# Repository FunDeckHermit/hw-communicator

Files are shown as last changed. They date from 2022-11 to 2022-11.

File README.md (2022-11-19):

# HW-communicator
Devices that can communicate state to one another. 

Project uses a Raspberry Pi Pico W, a Lora antenna, TP4056 lithium-ion cell charger to transmit a selected phrase.
This selected phrase is picked up by another module and displayed.

All firmware code is written in micropython. 

Todo: 
 * Wifi communication
 * LoraWAN communication
 * Pickup firmware
 
What would I do differently:
 * Add USB-B port somewhere
 * Add buzzer
 * Move 18650 holder a bit higher





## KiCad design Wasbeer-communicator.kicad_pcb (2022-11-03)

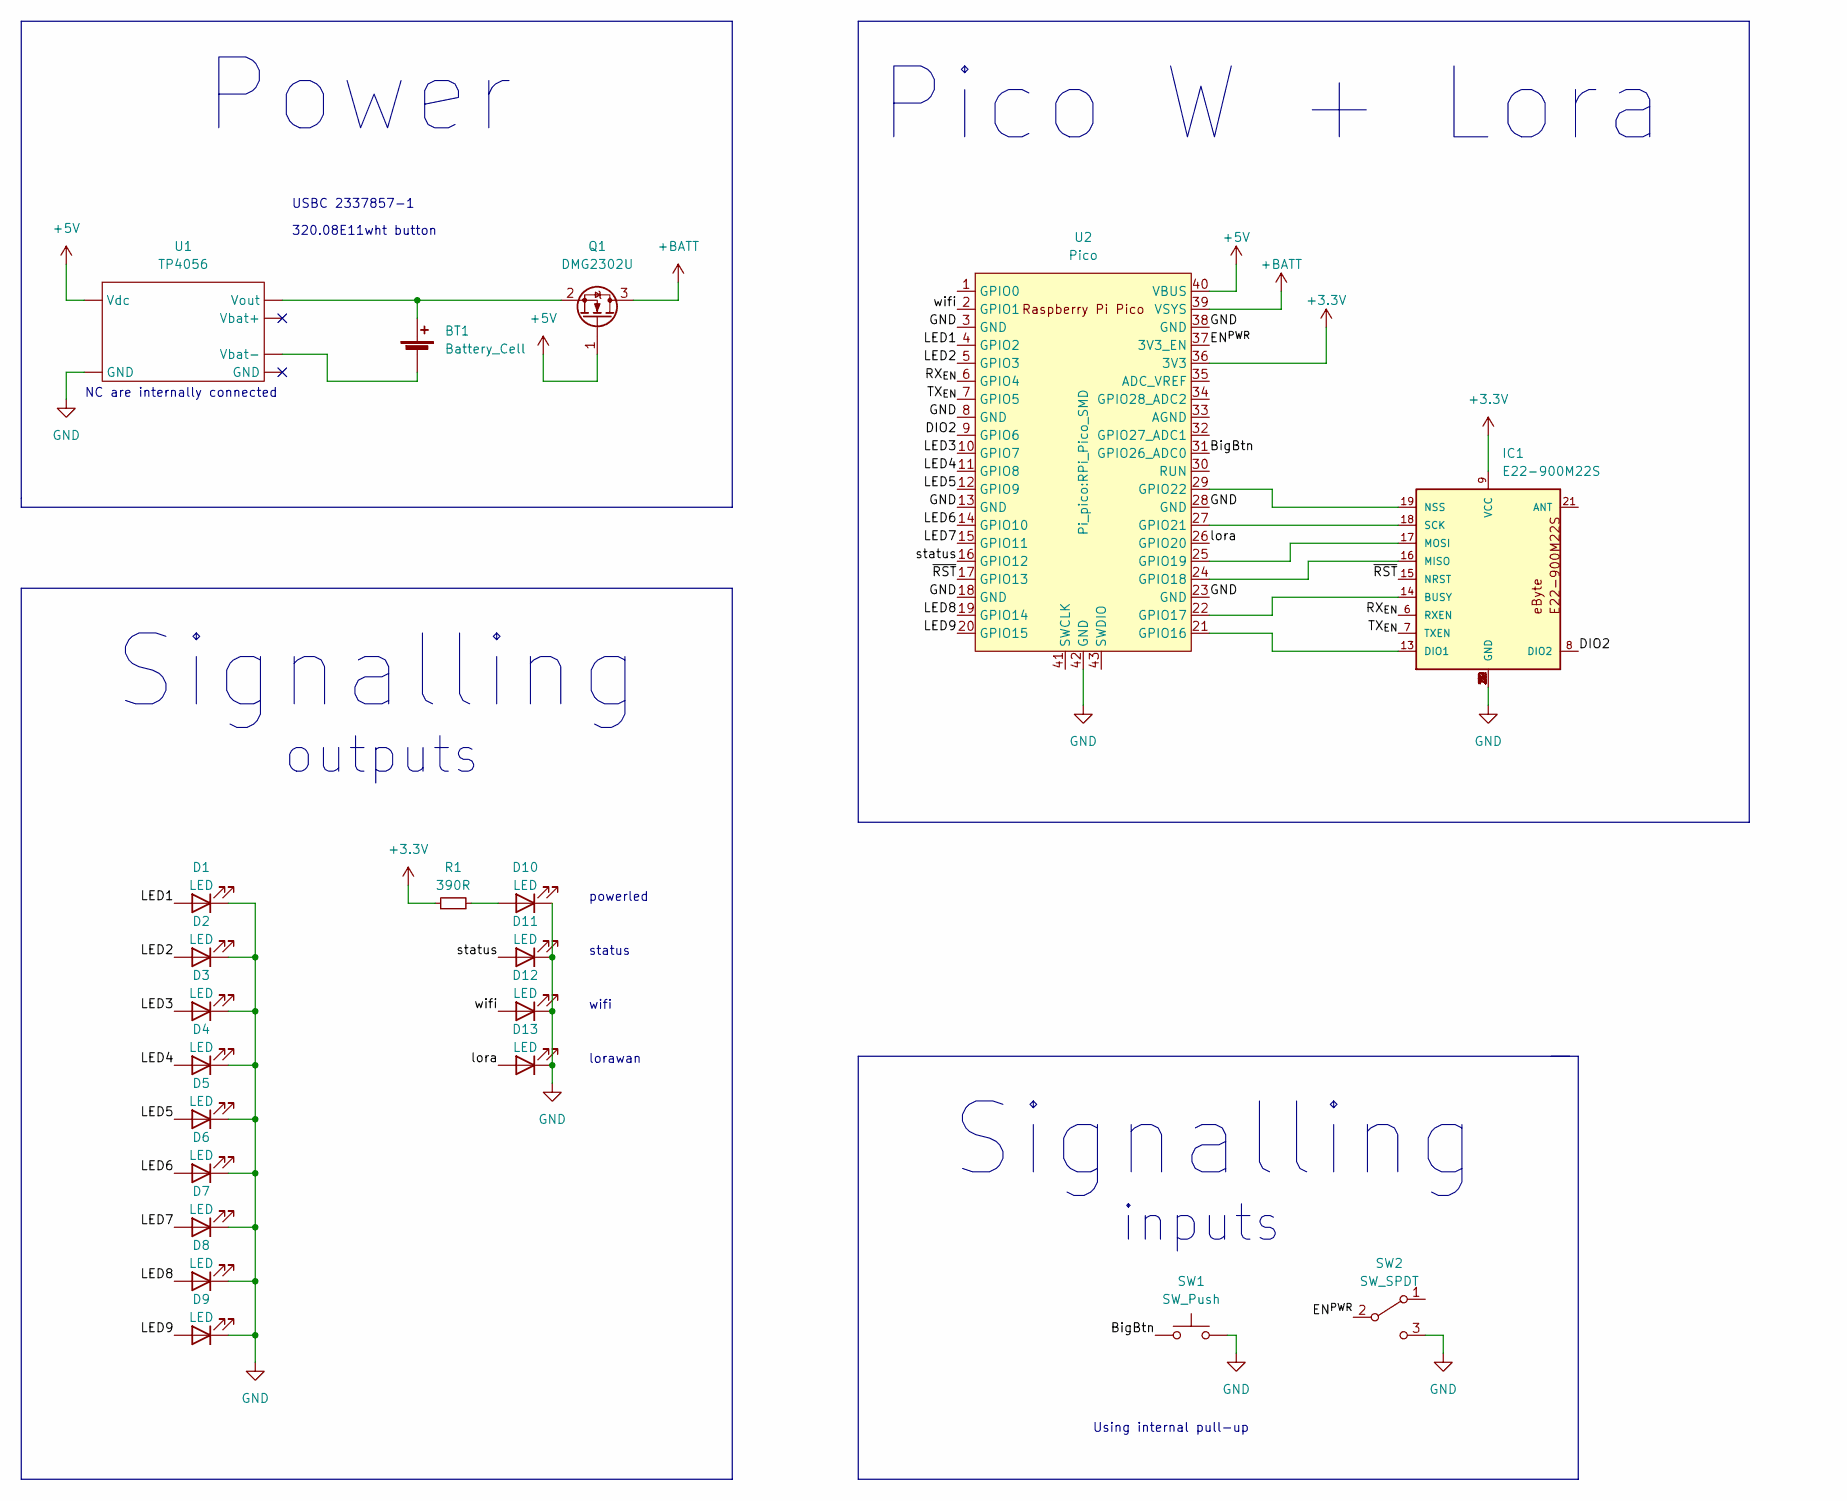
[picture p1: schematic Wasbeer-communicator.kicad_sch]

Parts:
BT1: Battery_Cell; 1042P
D1, D2, D3, D4, D5, D6, D7, D8, D9: LED; WL-SMDC
D10, D11, D12, D13: LED; LED_0603_1608Metric_Pad1.05x0.95mm_HandSolder
IC1: E22-900M22S
Q1: DMG2302U; SOT-23
R1: 390R; R_1206_3216Metric
SW1: SW_Push; 320.08E11wht
SW2: SW_SPDT; MSS3-Q-TR
U1: TP4056; TP4056-Module
U2: Pico; RPi_Pico_SMD

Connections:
+3.3V: IC1.9 (VCC), R1.1, U2.36 (3V3)
+5V: Q1.1 (G), U1.1 (Vdc), U2.40 (VBUS)
+BATT: Q1.3 (D), U2.39 (VSYS)
/BigBtn: SW1.1, U2.31 (GPIO26_ADC0)
/DIO2: IC1.8 (DIO2), U2.9 (GPIO6)
/EN^{PWR}: SW2.2 (B), U2.37 (3V3_EN)
/LED1: D1.2 (A), U2.4 (GPIO2)
/LED2: D2.2 (A), U2.5 (GPIO3)
/LED3: D3.2 (A), U2.10 (GPIO7)
/LED4: D4.2 (A), U2.11 (GPIO8)
/LED5: D5.2 (A), U2.12 (GPIO9)
/LED6: D6.2 (A), U2.14 (GPIO10)
/LED7: D7.2 (A), U2.15 (GPIO11)
/LED8: D8.2 (A), U2.19 (GPIO14)
/LED9: D9.2 (A), U2.20 (GPIO15)
/RX_{EN}: IC1.6 (RXEN), U2.6 (GPIO4)
/TX_{EN}: IC1.7 (TXEN), U2.7 (GPIO5)
/lora: D13.2 (A), U2.26 (GPIO20)
/status: D11.2 (A), U2.16 (GPIO12)
/wifi: D12.2 (A), U2.2 (GPIO1)
/~RST: IC1.15 (NRST), U2.17 (GPIO13)
GND: D1.1 (K), D2.1 (K), D3.1 (K), D4.1 (K), D5.1 (K), D6.1 (K), D7.1 (K), D8.1 (K), D9.1 (K), D10.1 (K), D11.1 (K), D12.1 (K), D13.1 (K), IC1.1 (GND), IC1.2 (GND), IC1.3 (GND), IC1.4 (GND), IC1.5 (GND), IC1.10 (GND), IC1.11 (GND), IC1.12 (GND), IC1.20 (GND), IC1.22 (GND), SW1.2, SW2.3 (C), U1.2 (GND), U2.3 (GND), U2.8 (GND), U2.13 (GND), U2.18 (GND), U2.23 (GND), U2.28 (GND), U2.38 (GND), U2.42 (GND)
unnamed: BT1.1 (+), Q1.2 (S), U1.3 (Vout)
unnamed: BT1.2 (-), U1.6 (Vbat-)
unnamed: D10.2 (A), R1.2
unnamed: IC1.13 (DIO1), U2.21 (GPIO16)
unnamed: IC1.14 (BUSY), U2.22 (GPIO17)
unnamed: IC1.16 (MISO), U2.24 (GPIO18)
unnamed: IC1.17 (MOSI), U2.25 (GPIO19)
unnamed: IC1.18 (SCK), U2.27 (GPIO21)
unnamed: IC1.19 (NSS), U2.29 (GPIO22)

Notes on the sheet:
USBC 2337857-1
Signalling
Pico W + Lora
NC are internally connected
Power
Using internal pull-up
lorawan
outputs
status
powerled
wifi
inputs
320.08E11wht button

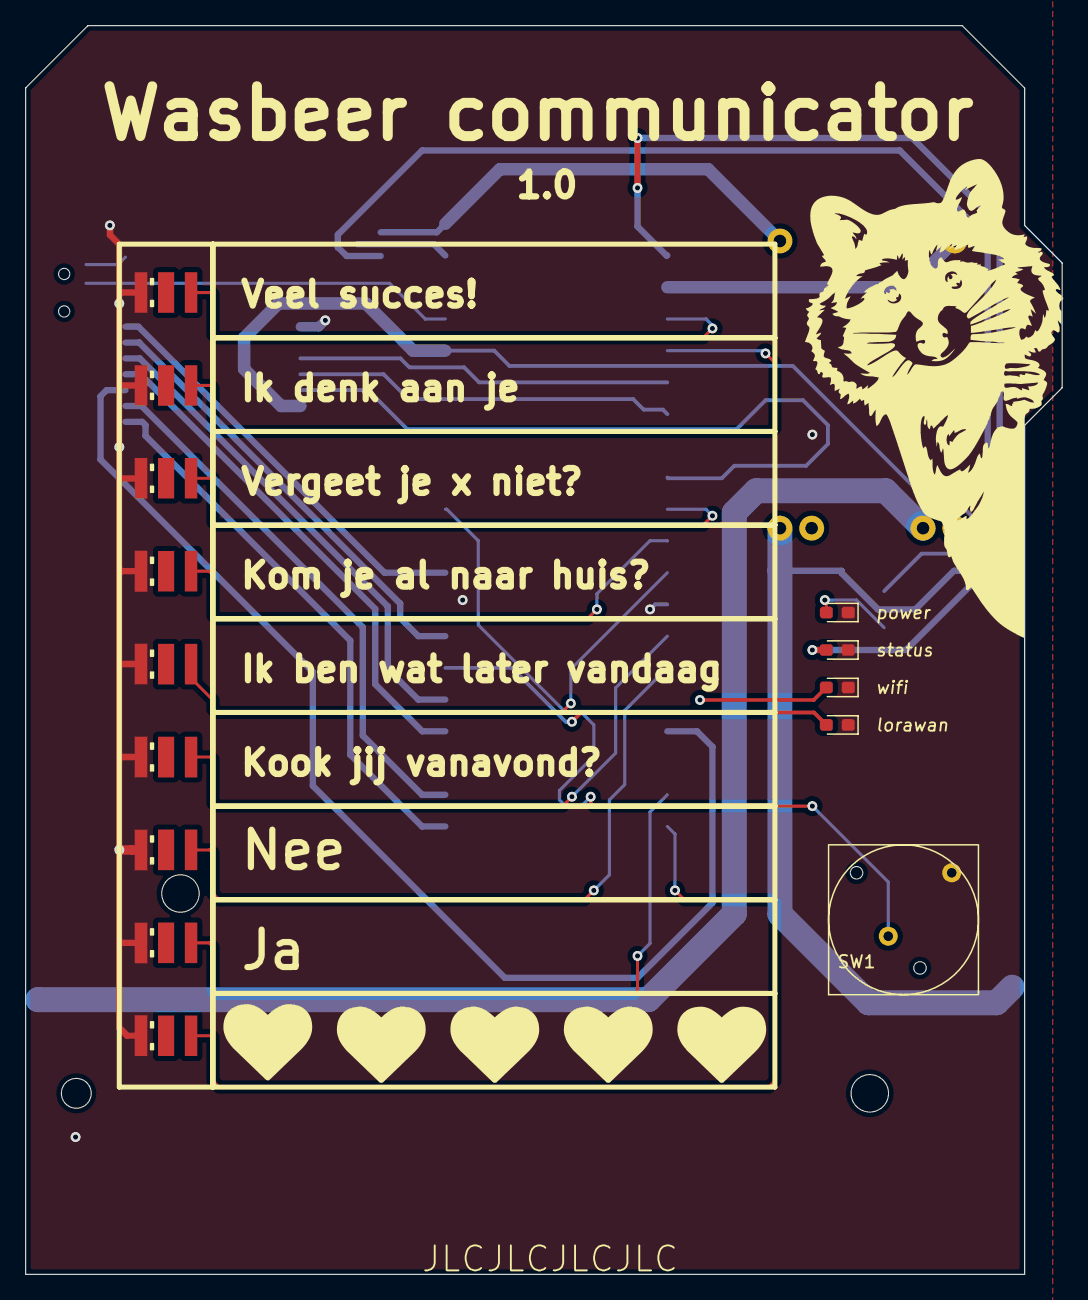
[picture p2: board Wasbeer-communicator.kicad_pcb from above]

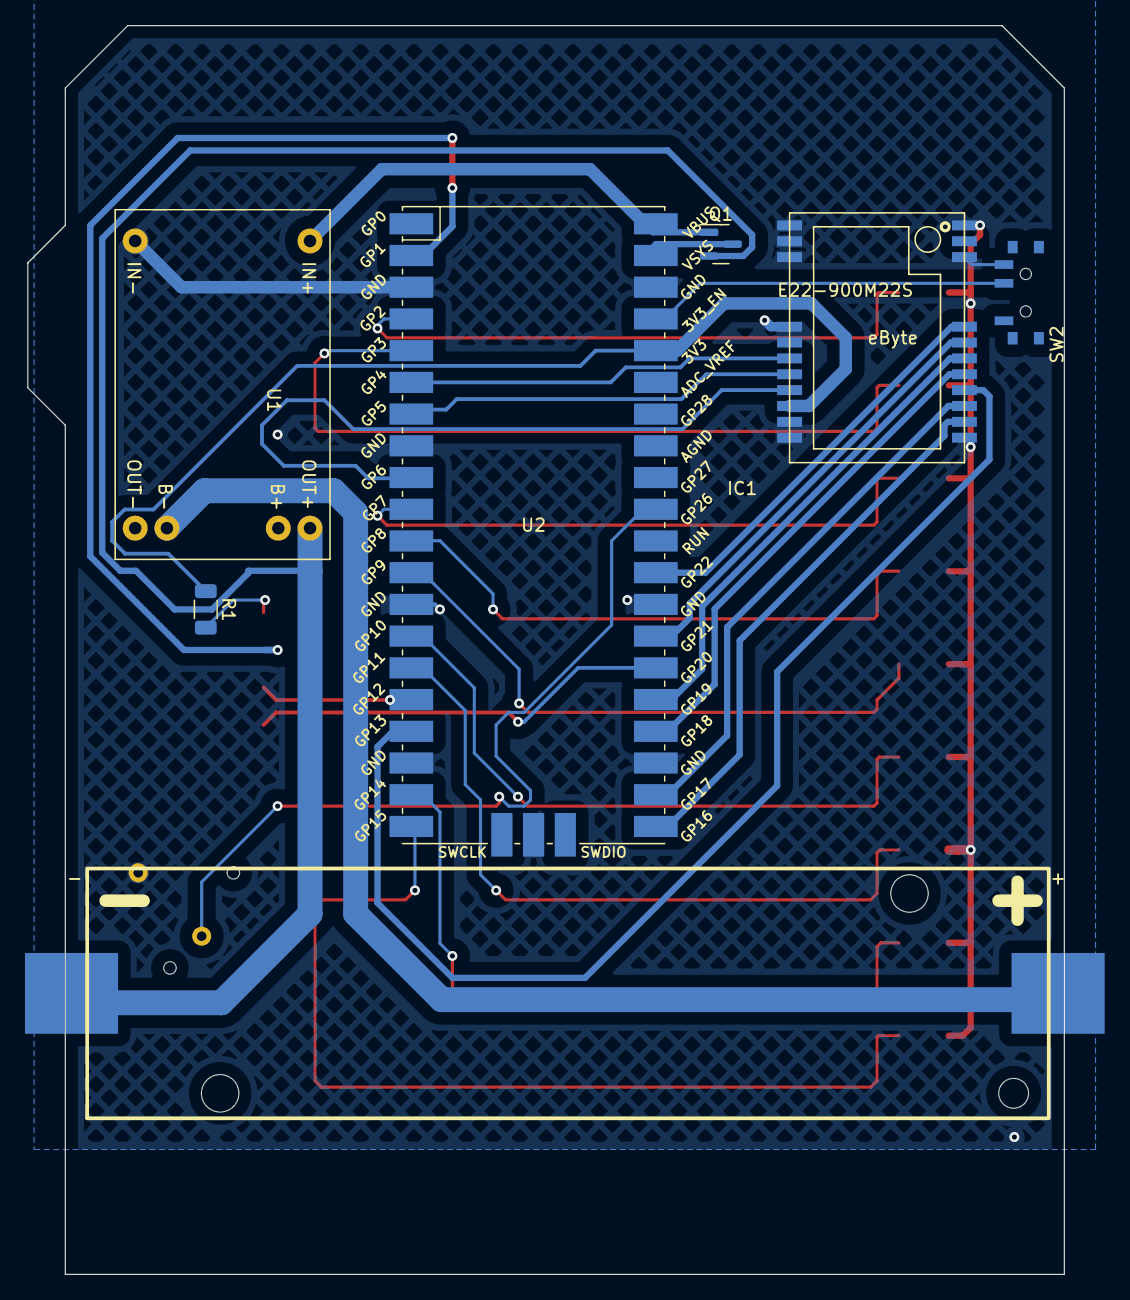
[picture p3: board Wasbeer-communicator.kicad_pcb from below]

Board: 2 copper layers, 83.0 x 100.0 mm, 21 parts (7 on the bottom side), 31 nets.

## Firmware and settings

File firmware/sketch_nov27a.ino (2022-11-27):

#include "RP2040_PWM.h"
#include "RPi_Pico_TimerInterrupt.h"

#define DEBOUNCETIME_MS 160
#define HOLDTIME_MS 1500
#define BLINKTIME_MS 142

#define big_button 26

#define led_status 1
#define led_wifi 12
#define led_lora 20
#define led1_heart 15
#define led2_ja 14
#define led3_nee 11
#define led4_kook 10
#define led5_later 9
#define led6_huis 8
#define led7_vergeten 7
#define led8_denk 3
#define led9_succes 2
#define NUM_OF_LEDS 9

uint led_array[] = {led1_heart, led2_ja, led3_nee, led4_kook, led5_later, led6_huis, led7_vergeten, led8_denk, led9_succes };

RP2040_PWM* PWM_Instance[NUM_OF_LEDS];
RPI_PICO_Timer ITimer0(0);
RPI_PICO_Timer ITimer1(1);

volatile int activeLED = -1;

bool Exclusive_On(int Index)
{
  for (uint i = 0; i < NUM_OF_LEDS; i++) {
    PWM_Instance[i]->setPWM(led_array[i], 20000, 0.5f);
  }
  if(Index < NUM_OF_LEDS && Index >= 0)
  {
    PWM_Instance[Index]->setPWM(led_array[Index], 20000, 10);
    return true;
  }
  return false;
}

void selectNextLed()
{
  activeLED = (activeLED + 1) % (NUM_OF_LEDS + 1);
  if(Exclusive_On(activeLED))
  {
    ITimer0.restartTimer();
  }
}

void onInterruptFalling() {
  static uint lasttime = 0;

  if ((millis() - lasttime) > DEBOUNCETIME_MS) {
    lasttime = millis();
    selectNextLed();
  }
}

bool TimerHandler0(struct repeating_timer *t)
{
  (void) t;
  ITimer0.stopTimer();
  Serial.println("Sending Signal to Wifi");
  ITimer1.restartTimer();
  return true;
}

bool TimerHandler1(struct repeating_timer *t)
{
  (void) t;
  volatile static uint timercount = 0;
  timercount++;

  if(timercount > 30)
  {
    ITimer1.stopTimer();
    timercount = 0;
    activeLED = -1;
    Exclusive_On(activeLED);
    Serial.println("Stop blinking!");
  }

  if(activeLED != 10 && activeLED != -1)
  {
    if(timercount % 2 == 1)
    {
      PWM_Instance[activeLED]->setPWM(led_array[activeLED], 20000, 0);
    }
    else
    {
      PWM_Instance[activeLED]->setPWM(led_array[activeLED], 20000, 10);
    }
  }
  return true;
}

void setup() {
  //Setup the pushbutton
  pinMode(big_button, INPUT_PULLUP);
  attachInterrupt(big_button, onInterruptFalling, FALLING);

  //Setup leds
  for (uint i = 0; i < NUM_OF_LEDS; i++) {
    PWM_Instance[i] = new RP2040_PWM(led_array[i], 20000, 0.5f);
    PWM_Instance[i]->setPWM();
  }

  //Setup timers
  ITimer0.attachInterruptInterval(HOLDTIME_MS * 1000, TimerHandler0);
  ITimer0.stopTimer();
  ITimer1.attachInterruptInterval(BLINKTIME_MS * 1000, TimerHandler1);
  ITimer1.stopTimer();  
}

void loop() {
  // put your main code here, to run repeatedly:
}

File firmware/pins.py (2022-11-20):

from machine import Pin, PWM


class Pins:
    def __init__(self):
        self.maxpwm = 2**16
        
        self.big_button = Pin(26, Pin.IN, Pin.PULL_UP)

        self.led0_inbuilt = Pin('LED', Pin.OUT)
        self.led_status = Pin(1, Pin.OUT)
        self.led_wifi = Pin(12, Pin.OUT)
        self.led_lora = Pin(20, Pin.OUT)

        self.led1_heart = PWM(Pin(15, Pin.OUT))
        self.led2_ja = PWM(Pin(14, Pin.OUT))
        self.led3_nee = PWM(Pin(11, Pin.OUT))
        self.led4_kook = PWM(Pin(10, Pin.OUT))
        self.led5_later = PWM(Pin(9, Pin.OUT))
        self.led6_huis = PWM(Pin(8, Pin.OUT))
        self.led7_vergeten = PWM(Pin(7, Pin.OUT))
        self.led8_denk = PWM(Pin(3, Pin.OUT))
        self.led9_succes = PWM(Pin(2, Pin.OUT))
            
        self.selectable_leds = [self.led0_inbuilt, self.led1_heart, self.led2_ja, self.led3_nee, self.led4_kook, self.led5_later, self.led6_huis, self.led7_vergeten, self.led8_denk, self.led9_succes]

    def set_max_pwm_u16(self, maxvalue):
        self.maxpwm = maxvalue
    
    def get_output_led_list(self):
        return self.selectable_leds
    
    def all_leds_off(self):
        for led in self.selectable_leds:
            self.led_off(led)
            
    def exclusive_on(self, onled_index):
        self.all_leds_off()
        self.led_on(self.selectable_leds[onled_index])
        
    def led_off(self, led):
        if type(led).__name__ is 'PWM':
            led.duty_u16(0)
        else:
            led.value(0)
    
    def led_on(self, led):
        if type(led).__name__  is 'PWM':
            led.duty_u16(self.maxpwm)
        else:
            led.value(0)

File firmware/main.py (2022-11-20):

from machine import Pin
from statemachine import LinearStateMachine, CallbackWaitingStateMachine
from wifi import connect
from pins import Pins

import time
import random

proj_pins = Pins()
ledlist = proj_pins.get_output_led_list()
proj_pins.set_max_pwm_u16(5000)


btn_sm = LinearStateMachine(n_states=10)
sel_sm = CallbackWaitingStateMachine(n_states=2)
interrupt_flag = 0
lastclick_time = 0
selected = 0
loop_count = 0


def check_choice():
    global btn_sm, selected
    if ledlist[btn_sm.index] is not proj_pins.led0_inbuilt:
        selected = btn_sm.index
        btn_sm.reset()
        result = True
        
    
def next_selection():
    global btn_sm, sel_sm
    if sel_sm.index is 0:
        sel_sm.next_state()
        btn_sm.next_state()
  
  
def debounce(pin):
    global lastclick_time
    if (time.ticks_ms()-lastclick_time) > 242:
        lastclick_time=time.ticks_ms()
        next_selection()


def increment_loopcount():
    global loop_count
    loop_count = loop_count + 1
     

def toggle_status():
    global loop_count
    proj_pins.led_status.value(loop_count % 50 == 0)


def update_leds():
    global btn_sm, sel_sm
    if sel_sm.index == 0:
        proj_pins.exclusive_on(btn_sm.index)
    elif sel_sm.index == 1:
        blink_selected()
    else:
        proj_pins.all_leds_off()
    
def blink_selected():
    global loop_count
    if(loop_count % 6 == 0):
        proj_pins.exclusive_on(selected)
    elif(loop_count % 3 == 0):
        proj_pins.all_leds_off()
        

proj_pins.big_button.irq(trigger=Pin.IRQ_FALLING, handler=debounce)
sel_sm.setwaitcallback(state_index=0, waittime=1000, callback=check_choice)
sel_sm.setwaittime(state_index=1, waittime=3000, auto=True)

if not connect():
    print("cannot connect to Wifi")

while True:
    time.sleep(0.042)
    increment_loopcount()
    toggle_status()
    update_leds()
    
    

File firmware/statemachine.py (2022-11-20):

from machine import Timer
import time

class LinearStateMachine:
    def __init__(self, n_states):
        self.index = 0
        self.n_states = n_states
        self.lasttransition = time.ticks_ms()
    
    def __str__(self):
        timepassed = time.ticks_ms() - self.lasttransition
        return f'Current state: {self.index}'
    
    def next_state(self):
        self.index = (self.n_states + self.index + 1) % self.n_states
        self.lasttransition = time.ticks_ms()
    
    def prev_state(self):
        self.index = (self.n_states + self.index - 1) % self.n_states
        self.lasttransition = time.ticks_ms()   
    
    def reset(self):
        self.index = 0



class WaitTimeStateMachine(LinearStateMachine):
    def __init__(self, n_states):
        super().__init__(n_states)
        self.waittimes = [-1 for x in range(n_states)]
        self.autoadvances = [False for x in range(n_states)]
        self.oneshottimer = Timer()
        
    def setwaittime(self, state_index, waittime, auto = False):
        if state_index >= 0 and state_index < self.n_states:
            self.waittimes[state_index] = waittime
            self.autoadvances[state_index] = auto
            self.oneshottimer = Timer()
            
    def next_state(self):
        wt = self.waittimes[self.index]
        if wt is -1:
            self.advance(self)
            return
        self.oneshottimer.deinit()
        self.oneshottimer.init(mode=Timer.ONE_SHOT, period=wt, callback=self.advance)
     
    def advance(self, *_):
        super().next_state()
        self.check_auto_next()
        
    def check_auto_next(self):
        if self.autoadvances[self.index]:
            self.next_state()
            


class CallbackWaitingStateMachine(WaitTimeStateMachine):
    def __init__(self, n_states):
        super().__init__(n_states)
        self.callbacks = [None for x in range(n_states)]   

    def setwaitcallback(self, state_index, waittime, callback, auto = False):
        super().setwaittime(state_index, waittime, auto)
        self.setcallback(state_index, callback)
 
    def setcallback(self, state_index, callback):
        if state_index >= 0 and state_index < self.n_states:
            self.callbacks[state_index] = callback                    
        
    def next_state(self):
        super().next_state()
    
    def advance(self, *_):
        print(f"Trying to advance from state {self.index}")
        if self.callbacks[self.index] and self.callbacks[self.index]() == False:
            """Callback set but unsuccesfull"""
            return        
        super().advance()
        
        

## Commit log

2022-11-02 Added battery holder
    [Sinterklaas-Lora.kicad_pcb, Sinterklaas-Lora.kicad_sch]
2022-11-02 Added eByte E22-900M22S module to schematic
    [Sinterklaas-Lora.kicad_pcb, Sinterklaas-Lora.kicad_sch]
2022-11-02 Added text
    [Sinterklaas-Lora.kicad_pcb, Sinterklaas-Lora.kicad_sch]
2022-11-02 another 3 hours of work
    [Sinterklaas-Lora.kicad_pcb]
2022-11-03 Finished design, created gerbers for lcsc
    [Sinterklaas-Lora.kicad_pcb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]
2022-11-19 Firmware: PWM the leds and enhanced state machine
2022-11-27 Micropython has a nasty bug, so changed to Arduino
    [server.py, sketch_nov27a.ino, wifi.py]
